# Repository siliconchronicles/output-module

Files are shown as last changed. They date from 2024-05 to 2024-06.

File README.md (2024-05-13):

# An 8-bit numeric display

This is a description of a display for showing values of an 8-bit signal. This is useful
for building and debugging breadboard digital circuits working with digital numbers.

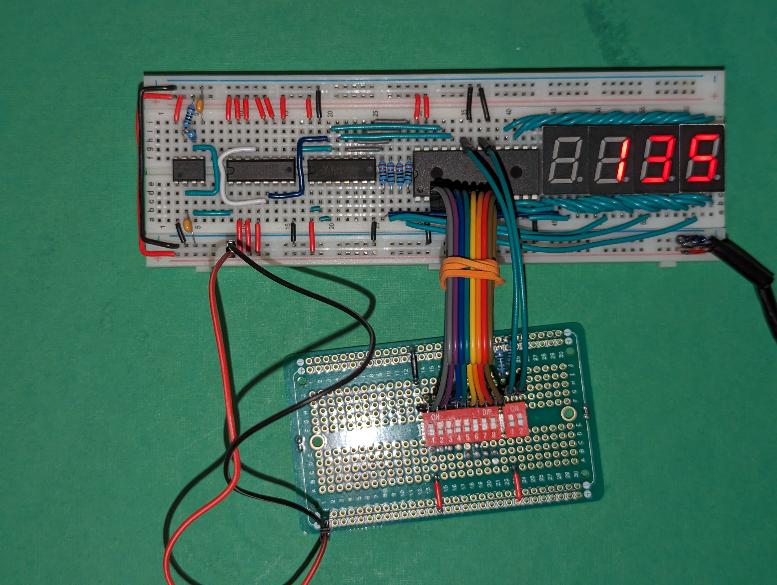
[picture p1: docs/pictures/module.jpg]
Picture of module


It's main features are:

* Can be switched (by a control signal) to display data in both decimal and hex.
* Can interpret data as unsigned numbers (0 to 255), or signed two's complement values (-128 to 127).
  This can also be switched through a control signal.
* has its internal clock, all the input it needs is the input data, power, and mode selection
  lines.

It's inspired in [Ben Eater's output register](https://eater.net/8bit/output), but this
is **just the display** (it does not contain register functionality). I decided to keep
it as a separate unit that I can attach to any register to debug.

[🎥 Video Demo](https://youtube.com/shorts/chPcDeSRnCQ?feature=share)

## Building the display

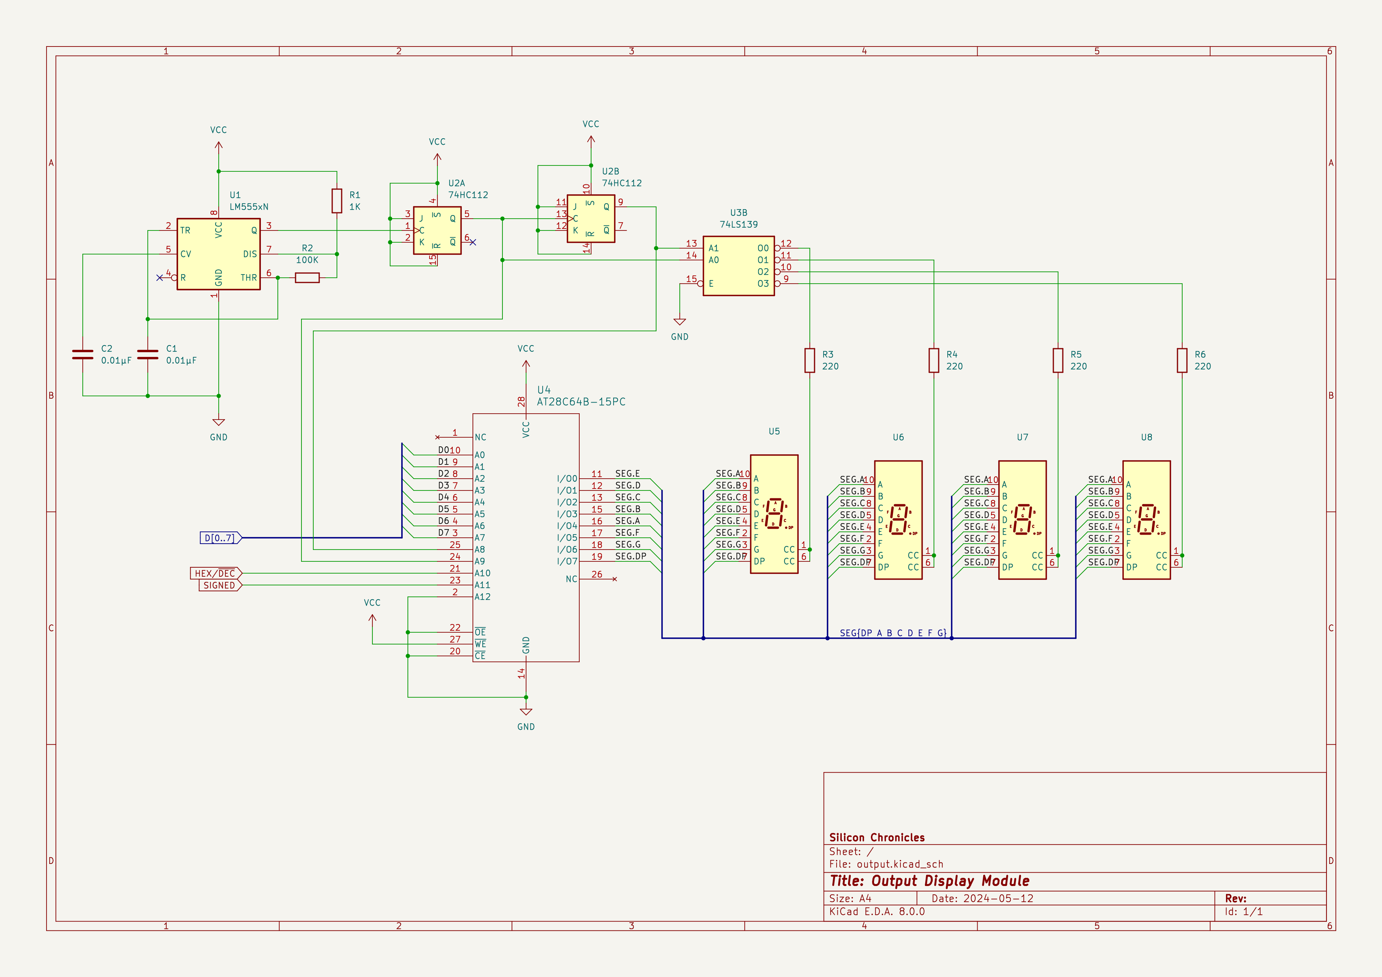
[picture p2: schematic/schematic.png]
Schematic


### Materials

* R1: 1KΩ
* R2: 100KΩ
* R3-R6: 220Ω (you can choose a slightly different value, this controls the brightness)
* C1, C2: 0.01µF (equivalent to 10nF) ceramic. Usually labeled "103"
* U1: LM555 timer IC
* U2: 74HC112 dual J-K flip-flops. This is different than Eater's design that used a 
  74LS76 (obsolete). Other J-K flip-flop ICs will work OK but may have different pin out.
* U3: 74HC139 dual 2:4 decoder
* U4: AT28C64B EEPROM. You'll have to pre-program it (see below)
* U5-U8: 7-segment display, common cathode. For breadboard use look for some with the
  pins at the top+bottom of the digit, and pins at the right spacing.

All ICs should be in DIP package if you're building in breadboards.

You can also choose TTL compatible components (LS or HCT families for the 74 series, and
NE555 for the timer IC). As long as you're consistent, it's the same; all external
inputs come into the EEPROM, which accepts both TTL and CMOS inputs.

### Data sheets

* [LM555](https://www.ti.com/lit/ds/symlink/lmc555.pdf)
* [74HC112](https://www.ti.com/lit/ds/symlink/sn74hc112.pdf)
* [74HC139](https://www.ti.com/lit/ds/symlink/sn74hc139.pdf)
* [AT28C64B](https://ww1.microchip.com/downloads/en/devicedoc/doc0001h.pdf)

## Preparing the ROM

The ROM image is generated by a [Python script](https://github.com/siliconchronicles/output-module/blob/main/mkrom.py). I tried to make it
easy to change. I'm also providing a [pre-built ROM file](output.bin) if you want to use mine unchanged.

You will need an EEPROM programmer to write the ROM. The image generated only uses the lower 4KB (leaving the other 4KB unused). It would
be possible to add other modes there if desired.

The `Config` section has a few settings that you can fiddle with; `FONT` is something you
can change without changing the circuit if you want to provide different selection of
segments or representable values. `ROM_LAYOUT` is used to customize the mapping of
segment to ROM pins; this has been configured for my breadboard layout so that the wires
from ROM to the segment stay in the same side of the breadboard and are tidier.

The `generate_text()` should produce the text representation for an 8-bit value in the
selected mode. `shuffle()` takes care of adjusting the bits described in the font to the
output pin layout selected.

If you set an invalid mode, the display should show `----` (four dashes).

## Possible improvements

* Having one resistor per digit makes the current fixed per digit, which results in symbols
  with many segments (like the digit 8) dimmer than symbols with less segments (like the
  digit 1). It would be better to have resistors in each one of the output lines from the
  ROM, but using a breadboard ends up being a bit tight to do this
* I'm exploring a version where I replace the 112+139 for a single PLA (ATF16V8); that
  would provide a bit of extra physical space for other improvements.

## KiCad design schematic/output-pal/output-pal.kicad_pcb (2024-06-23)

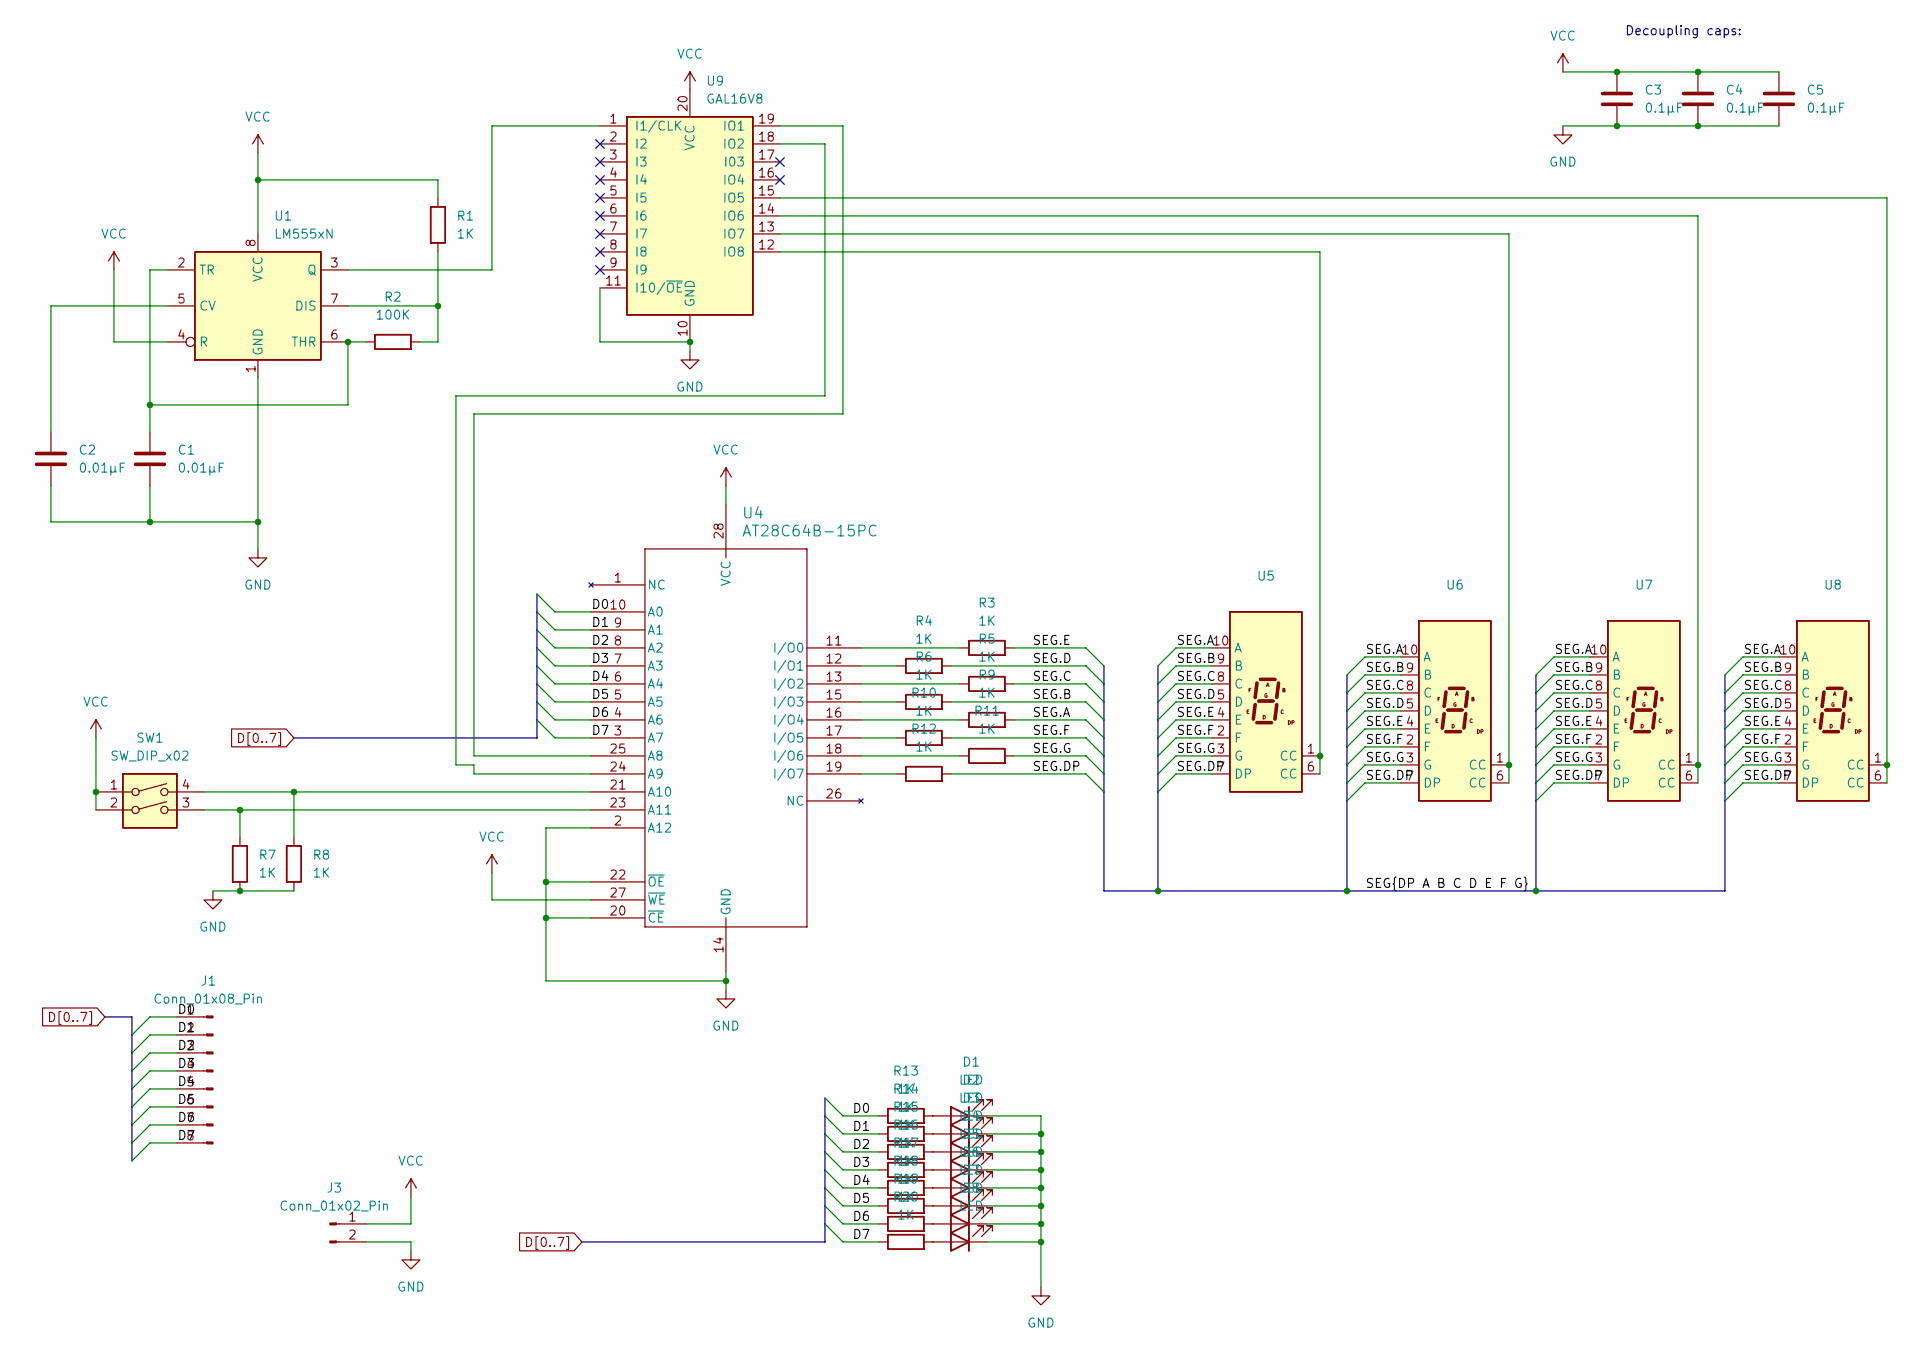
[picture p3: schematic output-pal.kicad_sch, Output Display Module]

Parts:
C1, C2: 0.01µF; C_1206_3216Metric_Pad1.33x1.80mm_HandSolder
C3, C4, C5: 0.1µF; C_1206_3216Metric_Pad1.33x1.80mm_HandSolder
D1, D2, D3, D4, D5, D6, D7, D8: LED; C_0805_2012Metric_Pad1.18x1.45mm_HandSolder
J1: Conn_01x08_Pin; PinHeader_1x08_P2.54mm_Vertical
J3: Conn_01x02_Pin; PinHeader_1x02_P2.54mm_Vertical
R1, R3, R4, R5, R6, R7, R8, R9, R10, R11, R12, R13, R14, R15, R16, R17, R18, R19: 1K; R_1206_3216Metric_Pad1.30x1.75mm_HandSolder
R2: 100K; R_1206_3216Metric_Pad1.30x1.75mm_HandSolder
R20: 1K; R_1206_3216Metric
SW1: SW_DIP_x02; SW_DIP_SPSTx02_Piano_10.8x6.64mm_W7.62mm_P2.54mm
U1: LM555xN; SOIC-8_3.9x4.9mm_P1.27mm
U4: AT28C64B-15PC; DIP-28_W15.24mm_Socket
U5, U6, U7, U8: HDSP-7503; 7SegmentLED_generic
U9: GAL16V8; DIP-20_W7.62mm_Socket

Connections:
/SEG.A: R9.2, U5.10 (A), U6.10 (A), U7.10 (A), U8.10 (A)
/SEG.B: R6.2, U5.9 (B), U6.9 (B), U7.9 (B), U8.9 (B)
/SEG.C: R5.2, U5.8 (C), U6.8 (C), U7.8 (C), U8.8 (C)
/SEG.D: R4.2, U5.5 (D), U6.5 (D), U7.5 (D), U8.5 (D)
/SEG.DP: R12.2, U5.7 (DP), U6.7 (DP), U7.7 (DP), U8.7 (DP)
/SEG.E: R3.2, U5.4 (E), U6.4 (E), U7.4 (E), U8.4 (E)
/SEG.F: R10.2, U5.2 (F), U6.2 (F), U7.2 (F), U8.2 (F)
/SEG.G: R11.2, U5.3 (G), U6.3 (G), U7.3 (G), U8.3 (G)
D0: J1.1, R13.1, U4.10 (A0)
D1: J1.2, R14.1, U4.9 (A1)
D2: J1.3, R15.1, U4.8 (A2)
D3: J1.4, R16.1, U4.7 (A3)
D4: J1.5, R17.1, U4.6 (A4)
D5: J1.6, R18.1, U4.5 (A5)
D6: J1.7, R19.1, U4.4 (A6)
D7: J1.8, R20.1, U4.3 (A7)
GND: C1.2, C2.2, C3.2, C4.2, C5.2, D1.1 (K), D2.1 (K), D3.1 (K), D4.1 (K), D5.1 (K), D6.1 (K), D7.1 (K), D8.1 (K), J3.2, R7.2, R8.2, U1.1 (GND), U4.2 (A12), U4.14 (GND), U4.20 (~CE), U4.22 (~OE), U9.10 (GND), U9.11 (I10/~OE)
unnamed: D1.2 (A), R13.2
unnamed: D2.2 (A), R14.2
unnamed: D3.2 (A), R15.2
unnamed: D4.2 (A), R16.2
unnamed: D5.2 (A), R17.2
unnamed: D6.2 (A), R18.2
unnamed: D7.2 (A), R19.2
unnamed: D8.2 (A), R20.2
unnamed: C2.1, U1.5 (CV)
unnamed: R1.2, R2.2, U1.7 (DIS)
unnamed: U1.3 (Q), U9.1 (I1/CLK)
unnamed: C1.1, R2.1, U1.2 (TR), U1.6 (THR)
unnamed: U4.25 (A8), U9.19 (IO1)
unnamed: U4.24 (A9), U9.18 (IO2)
unnamed: R8.1, SW1.4, U4.21 (A10)
unnamed: R7.1, SW1.3, U4.23 (A11)
unnamed: R3.1, U4.11 (I/O0)
unnamed: R4.1, U4.12 (I/O1)
unnamed: R5.1, U4.13 (I/O2)
unnamed: R6.1, U4.15 (I/O3)
unnamed: R9.1, U4.16 (I/O4)
unnamed: R10.1, U4.17 (I/O5)
unnamed: R11.1, U4.18 (I/O6)
unnamed: R12.1, U4.19 (I/O7)
unnamed: U8.1 (CC), U8.6 (CC), U9.15 (IO5)
unnamed: U7.1 (CC), U7.6 (CC), U9.14 (IO6)
unnamed: U6.1 (CC), U6.6 (CC), U9.13 (IO7)
unnamed: U5.1 (CC), U5.6 (CC), U9.12 (IO8)
VCC: C3.1, C4.1, C5.1, J3.1, R1.1, SW1.1, SW1.2, U1.4 (R), U1.8 (VCC), U4.27 (~WE), U4.28 (VCC), U9.20 (VCC)

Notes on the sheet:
Decoupling caps:

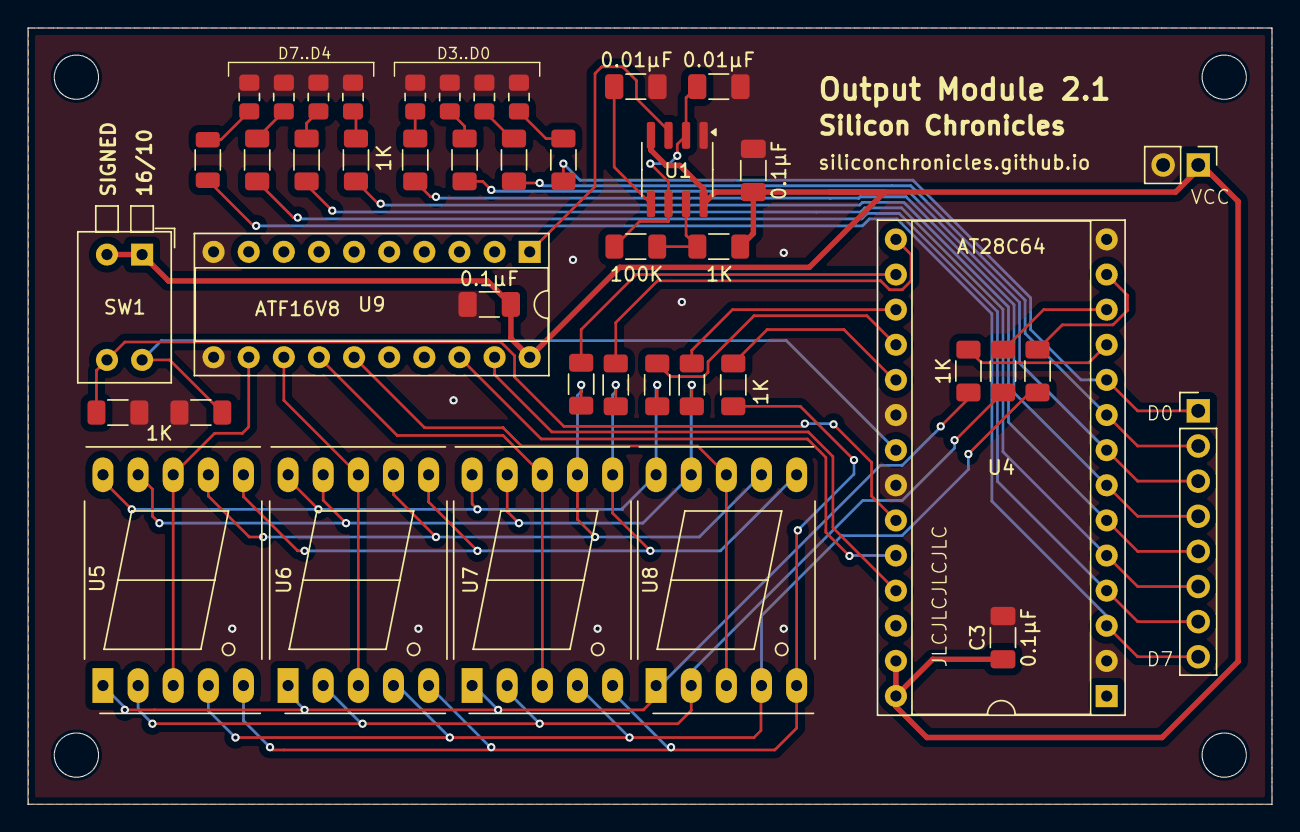
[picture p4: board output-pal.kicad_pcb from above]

Board: 2 copper layers, 90.0 x 56.1 mm, 43 parts (0 on the bottom side), 46 nets.

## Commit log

2024-05-13 Add some documentation
    [output.kicad_sch]
2024-06-21 Adjust pin order and numbering
2024-06-21 Add Schematic and PCB 2.0
    [output-pal.kicad_pcb, output-pal.kicad_sch]
2024-06-23 New release of output.
    Improved layout (more compact)
    Bigger LEDs
    More SMD components (including 7555 and capacitors)
    Front copper fill
    [output-pal.kicad_pcb, output-pal.kicad_sch]
2024-07-06 Remapped PIN numbers to final PCB build
